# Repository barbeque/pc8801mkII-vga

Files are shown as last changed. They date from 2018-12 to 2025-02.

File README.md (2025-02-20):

# PC-8801mkII VGA
This is a video adapter I built to go from my 1984 NEC PC-8801mkII's 3-bit digital RGB-out port to a VGA monitor. If you have an SR or newer, you can (and should) just use analogue RGB to VGA adapters instead.

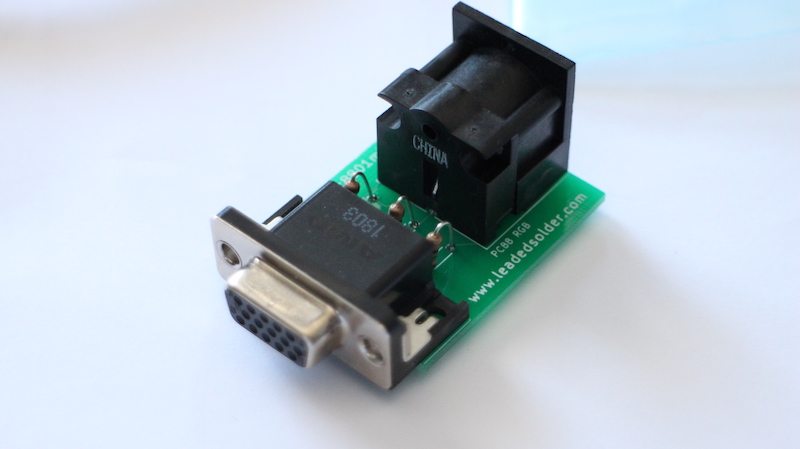
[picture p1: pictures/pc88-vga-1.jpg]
Assembled adapter

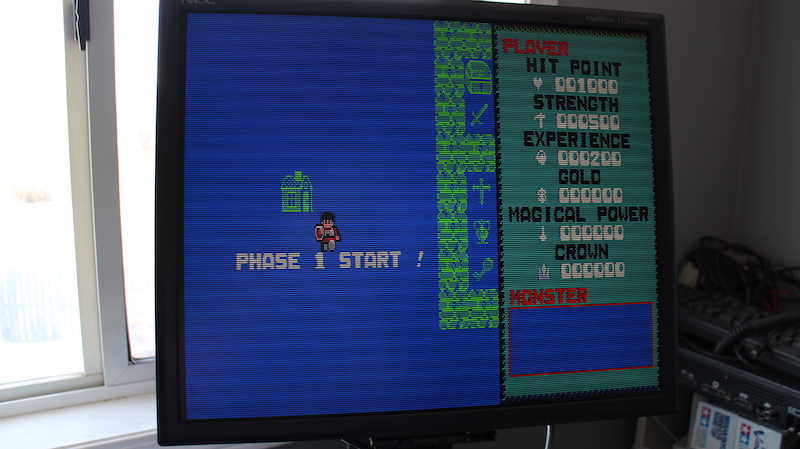
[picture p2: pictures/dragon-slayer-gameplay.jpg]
Dragon Slayer


Please note that this is just a level shifter and pinout adapter. It is _not_ a scan converter; if your monitor is not capable of 15kHz (or 24kHz for some machines) video, it will not work with this adapter. In other words, your monitor must match the output sync rate of the computer being adapted.

Please consult [the 15kHz modern monitors list](http://15khz.wikidot.com/) for models of monitor which may work with this adapter.

This board was developed as part of a project for [the Leaded Solder blog](https://www.leadedsolder.com/). Chances are, if you have a computer that needs this adapter, you will probably enjoy the other projects on the blog too. Please consider [backing the blog on Patreon](https://www.patreon.com/leadedsolder) to provide funds that will be used to make more open-source boards for the old-computer community.

# Current Status
**WORKING**, but improvements are likely to arrive in the coming days to deal with the "jailbar" interference pattern on some monitors.

# Version History
 - v1.8 (2025): In development.
 - v1.7 (2021): Added bypass capacitors that ruined the video quality. If you have one of these older boards (e.g. from PCBWay,) do not install the capacitors.

# Ordering a board
You can use files from the `gerber` directory, the zip files in the Releases section, or [order the board from the Shared Projects section of PCBway](https://www.pcbway.com/project/shareproject/NEC_PC_8801mkII_digital_RGB_video_to_VGA_adapter.html). Note that I receive a small PCBway credit for boards purchased through that platform.

# Bill of Materials
 * CUI SDS-80J 270-degree right-angle DIN female socket (CP-2380-ND)
 * TE AMP 1-1734530-1 VGA connector (A35116-ND)
 * 3x 150Ω through-hole resistors
 * 270° male-male 8-pin DIN cable (see below)
 
# Confirmed Working On
 * Fujitsu FM-7, Fujitsu FM-New7, Fujitsu FM-8
 * Hitachi Basic Master Level III Mark II
 * NEC PC-6001mkII (only 8 colour mode works, obviously)
 * NEC PC-8001, PC-8001mkIISR
 * NEC PC-8801mkII
 * NEC PC-9801UV
 * Sanyo MBC-550, MBC-555
 * Sony SMC-777 (8-colour mode)

# Display Devices Tested With
 * NEC MultiSync 1970NX LCD
 * NEC MultiSync 3D CRT
 * [GBS-Control upscaler](https://github.com/ramapcsx2/gbs-control)

# Assembly directions
 1. Solder both the VGA and DIN8 connectors to the board. The top side is the one marked with the LeadedSolder URL and the board name.
 2. Solder three 150Ω resistors into the spots for them in the middle of the board (Red, Green, Blue). The footprint is slightly too small for normal resistors, so I had to stand the resistor straight up and bend the other lead over.
 3. Connect the computer to the female DIN with a DIN8 extension cable such as the Ancable male-male 270° DIN8 cable (for Peavey Sanpera guitar pedals)
 4. Connect a 15/24kHz-capable VGA monitor (I use an NEC MultiSync 1970NX) to the female VGA connector with a standard VGA monitor cable.

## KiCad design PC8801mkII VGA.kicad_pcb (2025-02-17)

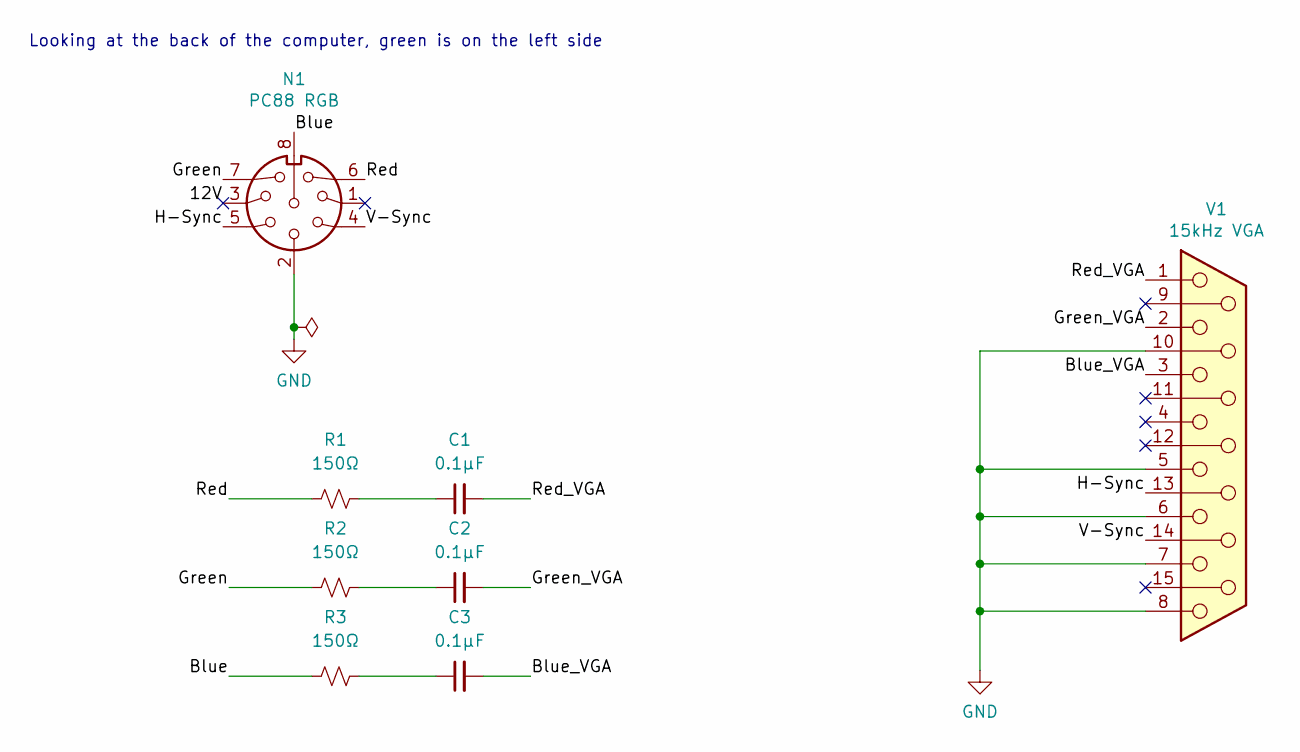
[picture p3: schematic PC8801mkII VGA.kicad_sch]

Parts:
C1, C2, C3: 0.1µF; C_Disc_D3.4mm_W2.1mm_P2.50mm
N1: PC88 RGB; CUI_SDS-80J
R1, R2, R3: 150Ω; R_Axial_DIN0207_L6.3mm_D2.5mm_P10.16mm_Horizontal
V1: 15kHz VGA; FIXED-1-1734530-1

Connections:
/12V: N1.3
/Blue: N1.8, R3.2
/Blue_VGA: C3.2, V1.3
/Green: N1.7, R2.2
/Green_VGA: C2.2, V1.2
/H-Sync: N1.5, V1.13
/Red: N1.6, R1.2
/Red_VGA: C1.2, V1.1
/V-Sync: N1.4, V1.14
GND: N1.2, N1.S1, N1.S2, V1.5, V1.6, V1.7, V1.8, V1.10, V1.16, V1.17
unnamed: C1.1, R1.1
unnamed: C2.1, R2.1
unnamed: C3.1, R3.1

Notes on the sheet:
Looking at the back of the computer, green is on the left side

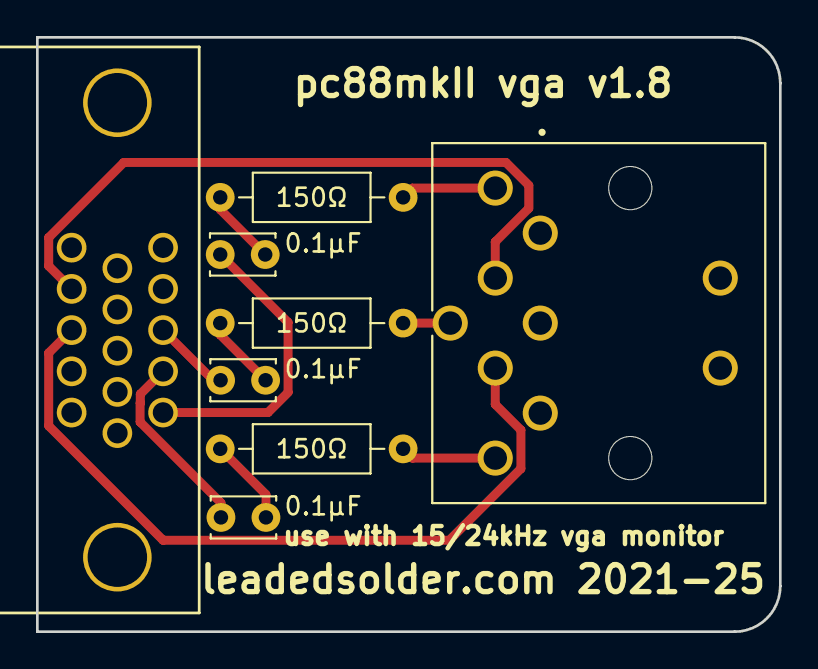
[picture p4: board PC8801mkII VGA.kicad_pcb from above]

Board: 2 copper layers, 41.3 x 33.0 mm, 8 parts (0 on the bottom side), 12 nets.

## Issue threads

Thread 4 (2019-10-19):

Fix ground bounce

barbeque, 2019-10-19:
There still seems to be some ground bounce. Maybe redesign this to have power and ground planes instead of just lines?

barbeque, 2019-11-23:
Added a huge ground plane on v1.6

Closed 2019-11-23.

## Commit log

2018-08-26 Really confusing board design that probably won't help me build this thing
    [PC8801mkII VGA.kicad_pcb, PC8801mkII VGA.sch]
2018-08-26 Use the 3-row right angle VGA connector which is all digikey seems to have
    [PC8801mkII VGA.kicad_pcb, PC8801mkII VGA.sch]
2018-08-26 Revision with ACTUAL PARTS
    [PC8801mkII VGA.kicad_pcb, PC8801mkII VGA.sch]
2018-08-26 Revised schematic based on the female pinout
    [PC8801mkII VGA.kicad_pcb, PC8801mkII VGA.sch]
2018-08-26 Add pointless silkscreen
    [PC8801mkII VGA.kicad_pcb]
2018-09-11 Label resistors
    [PC8801mkII VGA.kicad_pcb]
2018-09-19 Revised footprint
    [PC8801mkII VGA.kicad_pcb]
2018-09-19 Flipped version using fixed footprint
    [PC8801mkII VGA.kicad_pcb, PC8801mkII VGA.sch]
2018-09-19 Now with easier-to-cut sync traces
    [PC8801mkII VGA.kicad_pcb]
2018-09-20 Flipped the connector so it actually lines up now
    [PC8801mkII VGA.kicad_pcb]
2018-09-24 V1.4 - the colour pins go to the right places now
    [PC8801mkII VGA.kicad_pcb, PC8801mkII VGA.sch]
2018-09-24 Add warning label telling people the port is backwards from how it comes out of the PC88
    [PC8801mkII VGA.sch]
2018-09-26 Try to route the green trace a little further away from the sync pins
    [PC8801mkII VGA.kicad_pcb]
2018-10-01 Bigger resistors, trying to shorten colour tracks, run sync far away from all colours
    [PC8801mkII VGA.kicad_pcb, PC8801mkII VGA.sch]
2018-12-02 Add DIN8 to BOM
2019-11-22 Flipping 12V and Bonus aroundg
    [PC8801mkII VGA.sch]
2019-11-22 Wait - the pin numbers were right in the first place
    [PC8801mkII VGA.sch]
2019-11-23 Ground plane
    [PC8801mkII VGA.kicad_pcb]
2020-09-21 Fix the callout
    [PC8801mkII VGA.sch]
2020-09-21 Move 12V to the right side
    [PC8801mkII VGA.sch]
2020-09-21 Cleaning up
    [PC8801mkII VGA.sch]
2021-03-23 Use decoupling caps
    [PC8801mkII VGA.kicad_pcb, PC8801mkII VGA.sch]
2021-12-05 Provide Gerbers
    [PC8801mkII VGA-B_Cu.gbr, PC8801mkII VGA-B_Mask.gbr, PC8801mkII VGA-B_Paste.gbr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]
2021-12-05 Fixed readme, better gerbers
    [PC8801mkII VGA-B_Cu.gbr, PC8801mkII VGA-B_Mask.gbr, PC8801mkII VGA-B_Paste.gbr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]
2025-02-17 KiCad 8; bring up to spec
    [PC8801mkII VGA.kicad_pcb, PC8801mkII VGA.kicad_sch, PC8801mkII VGA.sch]
2025-02-17 v1.9 test release
    [PC8801mkII VGA-B_Cu.gbr, PC8801mkII VGA-B_Mask.gbr, PC8801mkII VGA-B_Paste.gbr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]
2025-02-20 PCBway link

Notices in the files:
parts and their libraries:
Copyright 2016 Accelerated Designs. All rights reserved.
